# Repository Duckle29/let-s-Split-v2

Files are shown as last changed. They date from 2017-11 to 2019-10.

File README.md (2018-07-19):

# This repo is now an archive. Further boards and development can be found here: https://github.com/Duckle29/Vitamins-included

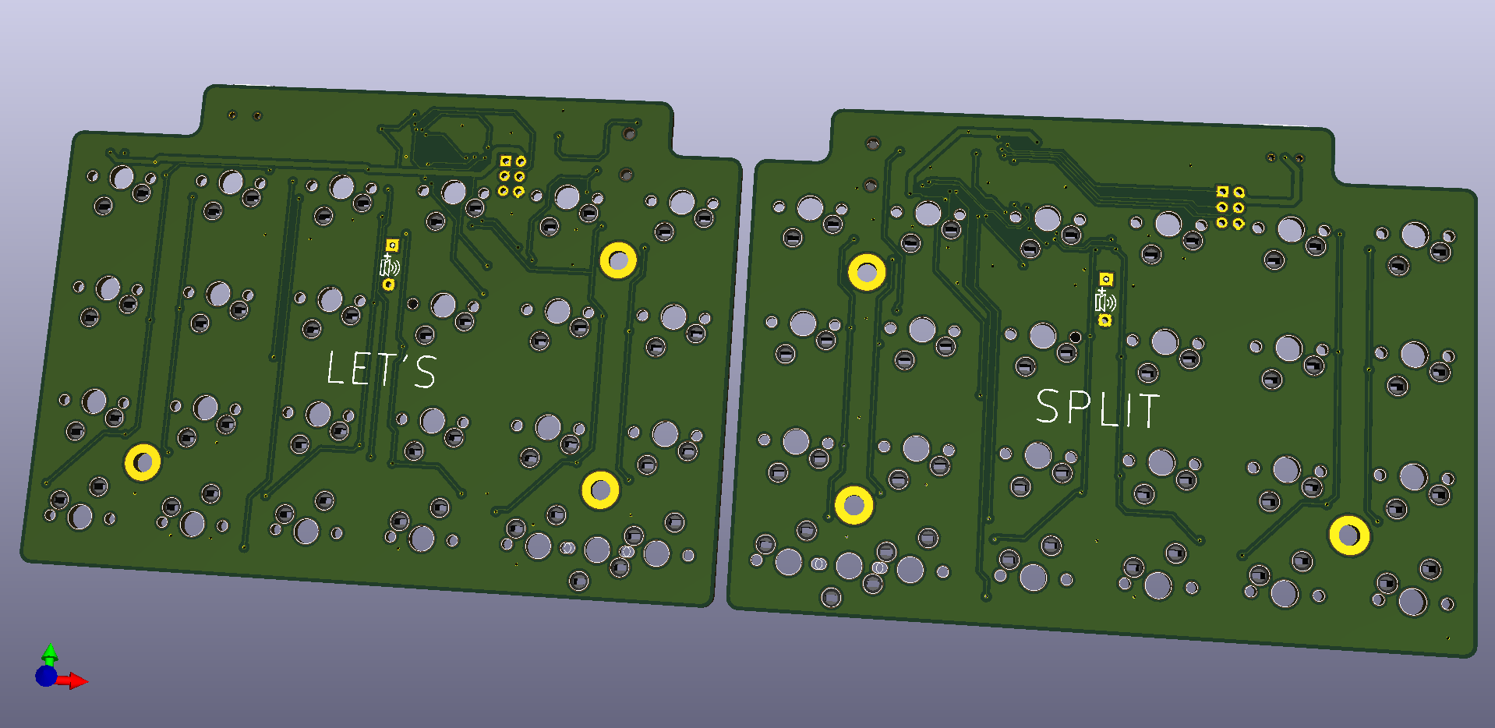
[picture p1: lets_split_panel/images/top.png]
Image of front side of panel

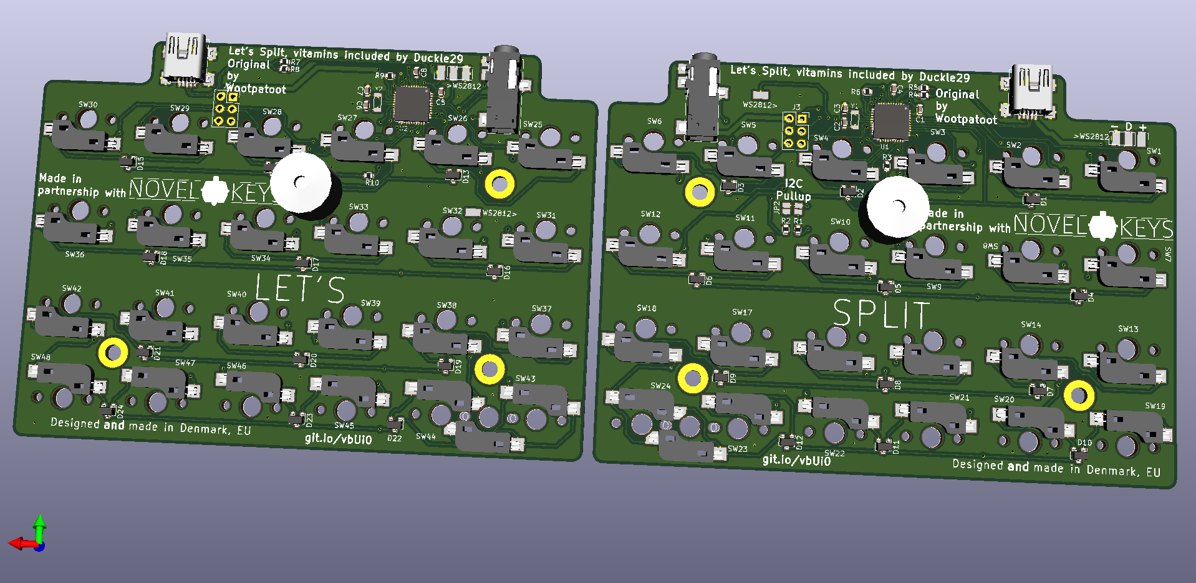
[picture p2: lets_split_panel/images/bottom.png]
Image of bottom side of panel


Schematic

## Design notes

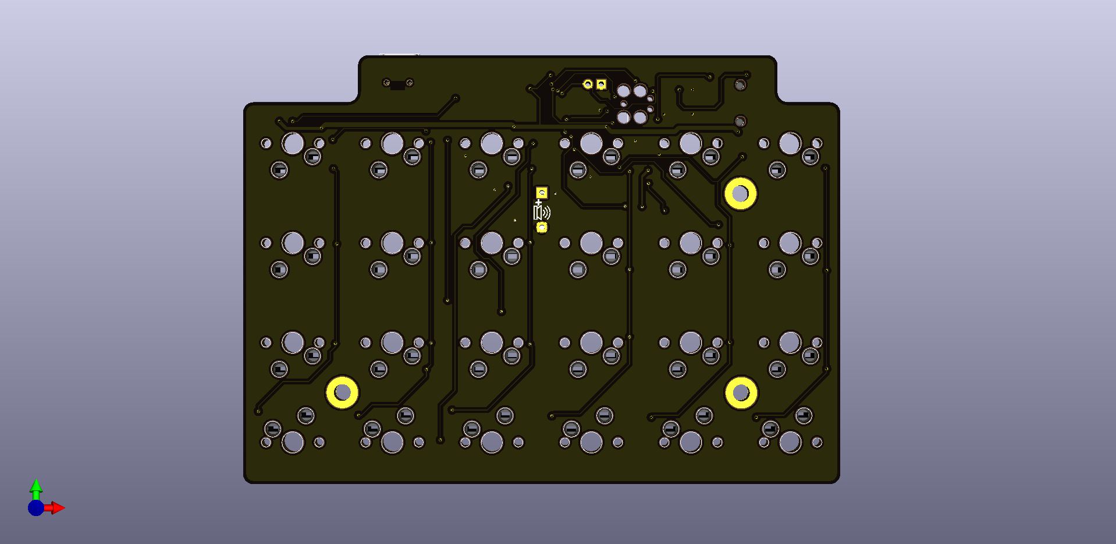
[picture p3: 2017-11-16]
lets_split/images/lets_split-top.png

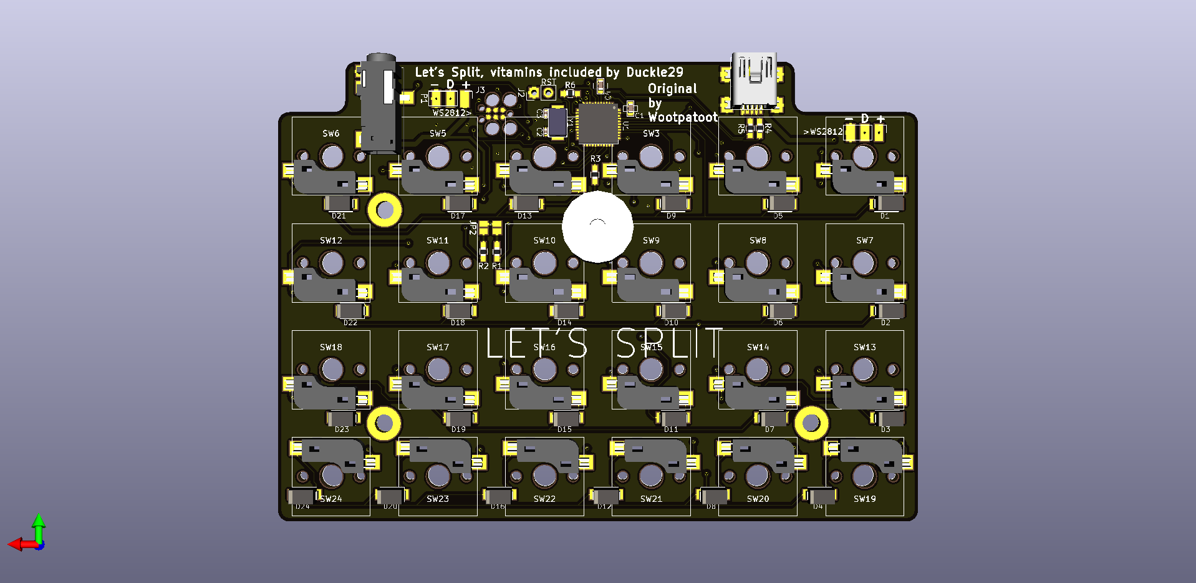
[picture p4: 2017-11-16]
lets_split/images/lets_split-bot.png

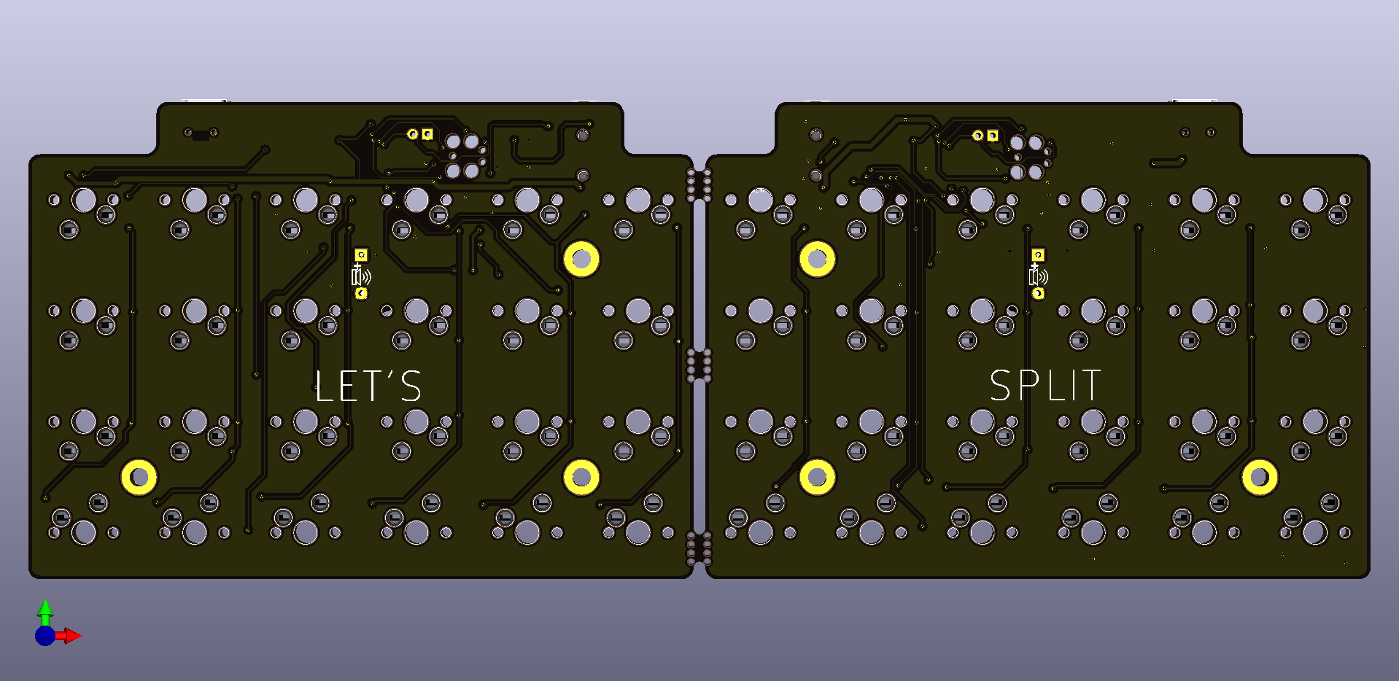
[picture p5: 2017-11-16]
lets_split_panel/images/topside.png

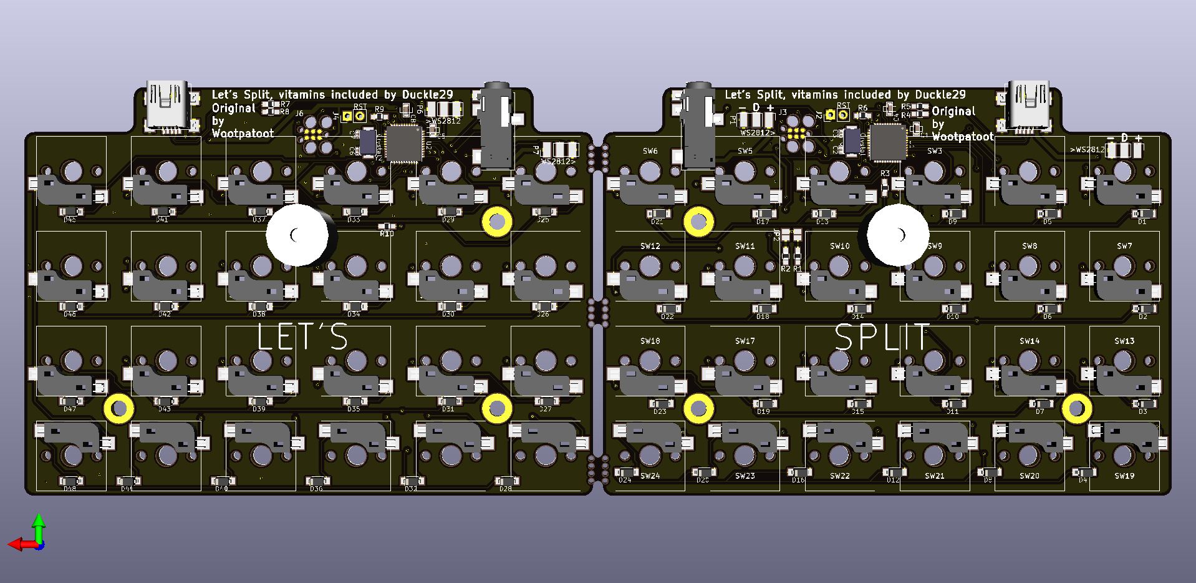
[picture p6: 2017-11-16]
lets_split_panel/images/bottomside.png

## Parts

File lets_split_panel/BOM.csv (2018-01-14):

Id | Designator | Package | Quantity | Designation | Supplier and ref
1 | G***,G*** | kiwi | 2 | LOGO
2 | FID6,FID4,FID5,FID3,FID2,FID1 | Fiducial_1mm_Dia_2mm_Outer | 6 | Fiducial
3 | P5,P2 | USB-Mini-B-SMD | 2 | UJ2-MBH-1-SMT
4 | D21,D16,D23,D14,D20,D22,D19,D24,D17,D15,D13,D18,D2,D8,D6,D12,D3,D7,D10,D4,D9,D11,D5,D1 | SOT-23 | 24 | BAV70
5 | R7,R8,R5,R4 | R_0603 | 4 | 22R
6 | SW40,SW36,SW41,SW43,SW44,SW42,SW45,SW43,SW35,SW28,SW34,SW48,SW47,SW33,SW39,SW32,SW26,SW29,SW46,SW30,SW38,SW27,SW31,SW25,SW37,SW19,SW12,SW21,SW23,SW24,SW24,SW6,SW15,SW4,SW5,SW13,SW20,SW1,SW22,SW16,SW17,SW8,SW10,SW11,SW7,SW9,SW18,SW2,SW14,SW3 | Kailh-socket | 50 | Socket
7 | Y2,Y1 | Crystal_SMD_Abracon_ABM3-2pin_5.0x3.2mm | 2 | 16MHz
8 | P6,P3 | SMD_PAD_1x03_Pitch2.54mm | 2 | >WS2812
9 | P8,P4 | SJ-4351X-SMT | 2 | SJ-43514-SMT
10 | J8,J7 | Pin_Header_Straight_1x01_Pitch2.54mm | 2 | WS2812>
11 | C6,C7,C2,C3 | C_0603 | 4 | 18pF
12 | C5,C8,C1,C4 | C_0603 | 4 | 1uF
13 | REF**,REF**,REF**,REF**,REF**,REF** | 1pin | 6 | 1pin
14 | U2,U1 | QFN44G-0.5-7X7MM | 2 | ATMega32U4
15 | R10,R3 | R_0603 | 2 | 200R
16 | R9,R1,R2,R6 | R_0603 | 4 | 4k7
17 | J6,J3 | Pin_Header_Straight_2x03_Pitch2.54mm | 2 | ISP
18 | J5,J1 | Buzzer_12x9.5RM7.6 | 2 | Speaker
19 | G***,G*** | NovelKeys | 2 | LOGO
20 | JP1,JP2 | Solder-jumper-NO | 2 | I2C pullup

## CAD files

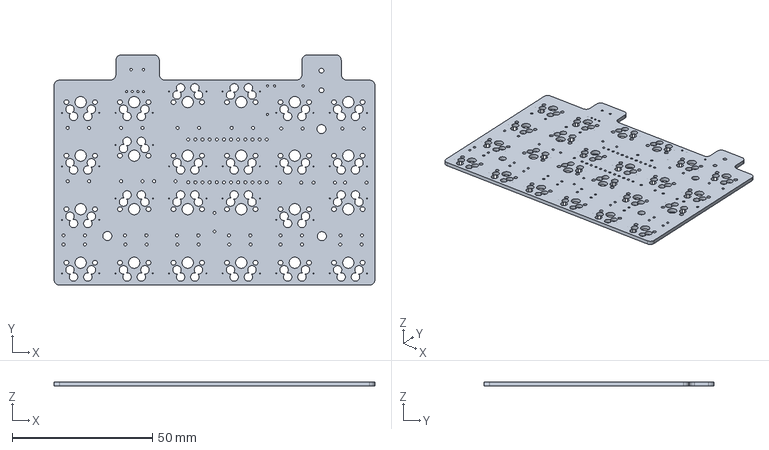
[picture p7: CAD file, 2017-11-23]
lets_split/pcb.step
114.2 x 82.0 x 1.60 mm

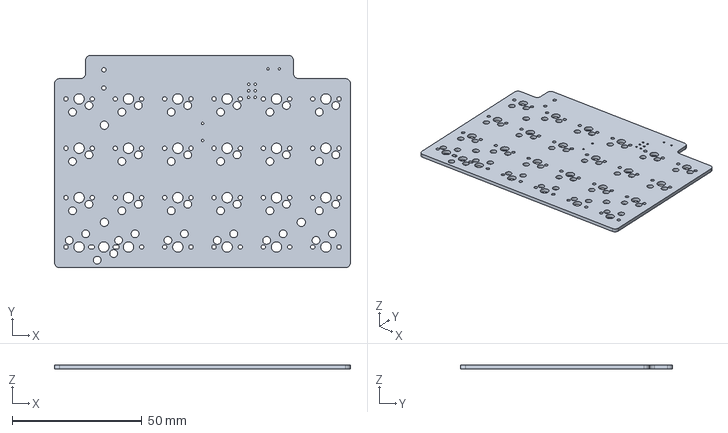
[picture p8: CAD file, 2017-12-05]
lets_split_panel/lets_split_righthalfpanel.stp
114.2 x 82.0 x 1.60 mm

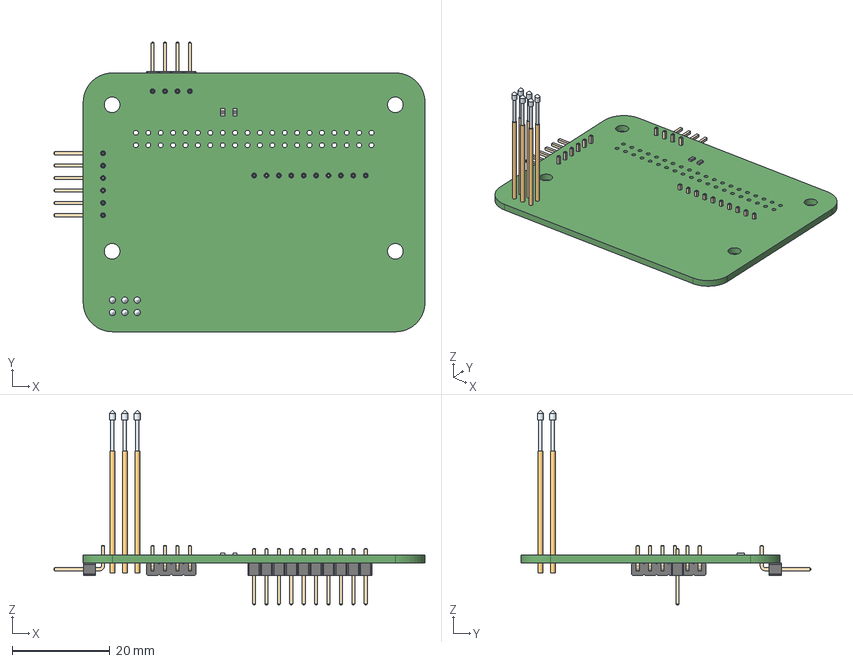
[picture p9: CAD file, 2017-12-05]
lets_split_panel/Programming-jig/prog-jig.stp
76.0 x 59.3 x 39.8 mm
Socket_Strip_Straight_2x20_Pitch2.54mm

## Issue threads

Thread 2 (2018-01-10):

Questions about the latest version

geripgeri, 2018-01-10:
Hi!

First of all, thanks for your work!

I would like to order the PCB via https://jlcpcb.com/
I don't really understand the main differences between version 2 and version 3, could you please describe them to me? Also, is the version 3 branch stabile and working? Do you recommend to use version 3?

Another question: is the version 3 branch compatible with Gateron 5 pin Switches? (Sorry for the noob question, this will be my first DIY keyboard) Can I attach led to the switches? I don't see any holes for leds, Are there any solutions for that?
Like this: 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

Thank you!

Duckle29, 2018-01-10:
Hey there. The latest stable is onboardMCU and I actually have a batch of those on their way, so if you don't want to solder, then those are soon ready.

They, like the V3, don't support in switch LEDs though, but if you know KiCAD it shouldn't be a big change. Just get the source files, and make a footprint for sockets + leds, then update all switches to that footprint, and then re-route the traces. Should be doable in an hour or two.

I will probably be looking into leds if I make any further versions :)

Duckle29, 2018-01-10:
Also, V3 adds the mini-usb breakout, so that your cable can come out the back of the keyboard:

https://i.imgur.com/UIVkkyn.jpg

geripgeri, 2018-01-11:
Thank you for the response!

I think this question has been overlooked:
> Another question: is the version 3 branch compatible with Gateron 5 pin Switches?

I checked the `onboardMCU` branch, looks pretty cool :+1: I can't find the assembly docs, parts list here: https://github.com/Duckle29/lets-split-guide is this because the mentioned batch is the first?

> I actually have a batch of those on their way, so if you don't want to solder, then those are soon ready.
Could you please send me an email about the details? :slightly_smiling_face:

Duckle29, 2018-01-11:
Yes, it's the first batch :) When you mentioned Gateron 5 pin switches, I assume you mean any MX switch with LEDs in them right? That's why I mentioned LEDs :)

geripgeri, 2018-01-12:
> I actually have a batch of those on their way, so if you don't want to solder, then those are soon ready.

Could you please send me an email about the details? 🙂 My email address is visible on my GitHub profile.

No, I meant this: 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

geripgeri, 2018-01-12:
Also, What is the difference between (in onboardMCU branch) `lets_split` and `lets_split_panel` folder?

Duckle29, 2018-01-12:
Ahh those. AFAIK those are just PCB mounted switches, and yes. Those are actually preferred! :)

lets_split_panel was the first batch, where I made the PCBs but not mirrored / flippable, so I had to panelize them. Fucked up and had the switches on the bottom of the keyboard on the right-side by accident, so gave up and decided to make the mirrorable design instead.

Duckle29, 2018-01-12:
Also, for the vitamins included batch. Expect to see it late feb :)

geripgeri, 2018-01-12:
Thanks for the info!

Can you please write down the components of the onboardMCU? Maybe it's better if you write it to the guide repository : I would like to estimate the costs of the PCB.

Duckle29, 2018-01-14:
I can upload the position files that I sent the Pick and place house, it has component names in there iirc.

Duckle29, 2018-01-14:
Done https://github.com/Duckle29/let-s-Split-v2/commit/f37b36a4e8799997df2698dced4c34b87e96ebc7

geripgeri, 2018-01-15:
Thank you!
In the meantime, there is a sale on https://jlcpcb.com
I have a few more questions about the PCB ordering, can I please contact you directly? I don't want to spam the GitHub issue. Could you please send me an email?

Duckle29, 2018-01-21:
@geripgeri Hey man, I don't mind the chat in here :) That way questions can help others

thesourmango, 2018-03-29:
Nice to see you chatting here, I had pretty much the same questions.
I'm dreaming of adding a bottom row, making it 60% and making both halves wireless... #endgame?

I found a wireless lets-split called Trident (https://github.com/YCF/Trident) but it seemed to have some issues, and I'm not comfortable or familiar with the Mitosis firmware it seemed to be running.
Also no sockets.

Anyway, It's been a couple months, have any onboardMCU boards to sell? If not, have you ran into any issues with the current design?

Is there anyone working on an open source 60% wireless socketed split? Like [this](https://www.reddit.com/r/mechmarket/comments/7ywlmb/gb_40_60_and_70_wireless_split_ortholinear/) but open source (and socketed)? No offense to southpaw intended, most of us need to make a living :p

Keep up the awesome work!

Duckle29, 2018-03-29:
@thesourmango Hey there :) The onboard MCU boards are most likely going to be called Vitamins Included, and will be sold by Novelkeys some time in april if everything goes to plan :) Mike is currently working on having cases made for them, which is one issue I've had with these boards. Due to the switches being socketed, you can't rely on them to hold the PCB in place, so the plate and the PCB have to be fixed.

I also haven't put a diode between VCC and VBUS, which gave me some headache in firmware support, but I have since manged to solve that fully in my opinion :) Hell, in the process I even made RGB work regardless of which half is plugged in.

As for a dual wireless, that's very very interesting, and is in fact something I'm working on :)
Currently I'm a bit pressed for time (Job hunting, studying for EE, and looking for sponsors for a LAN event sucks the time out of the schedule :) )

If you're curious, I've been looking at using the adafruit bluefruit NRF52 based board, but I might look for cheaper options. Regardless I'll have to write a new firmware from scratch, or need a lot of help to port QMK :)

thesourmango, 2018-03-29:
Nice, I'll keep an eye out for Vitamins Included! Although I'd want to build mine from the PCB up!
I think it's awesome you're going this way, first open source, then when it works, provide a kit or a full package.

RGB? Oh yes, please upload the pcb files with pads for leds :sweat_smile:  :drooling_face:

I don't suppose there's anything I can help you with the wireless 60% split? You haven't opened a git for it yet? :wink:  (Last year Embedded Student from Finland, ... turn it into my masters project?)

I love ortho for the looks, something magical about two squares on the desk. That being said, there are  some problems moving back and forth from an ANSI ortho to ISO Nordic Staggered when programming. :smile: So I'm now wondering if staggered would make more sense..

The mistel barocco RGB is pretty nice, the price tag isn't even that bad. [The Uruk](https://www.reddit.com/r/MechanicalKeyboards/comments/6nbvdu/ic_the_uruk_a_65_staggered_split_board/) is in development, but I'm a strong believer that the backspace is supposed to be the key in the top-right corner, so that one is out of question for me :smiley:. Also I didn't find any mention of publishing his designs.. :confused:

Duckle29, 2018-03-29:
@thesourmango You can see some images of the board here :) https://imgur.com/a/sle0V

The RGB is for underglow, not for per-key RGB, but I might look in to that in the future. I have to find some backfire LEDs though, so I can keep the boards single sided load (only components on one side) as going dual-sided drives up cost. I know kaihua makes some, so I might try and get in touch there.

I'm also not quite sure if the next board will be QMK based. It might be, or it might be KiiBohd based, or custom firmware. We'll see :)

As for a repo on it, You're right. There isn't one, because I've only gotten as far as buying a bluefruit from adafruit ;)

As for the URUK, that looks sweet :)

rockydbull, 2018-04-24:
Any chance you have a part number for the trrs socket and mini usb port? I am looking to order some blank pcbs and give these a run as macropads.

geripgeri, 2018-05-04:
@Duckle29 Hi!

>  @thesourmango Hey there :) The onboard MCU boards are most likely going to be called Vitamins Included, and will be sold by Novelkeys some time in April if everything goes to plan :) Mike is currently working on having cases made for them, which is one issue I've had with these boards. Due to the switches being socketed, you can't rely on them to hold the PCB in place, so the plate and the PCB have to be fixed.

Based on your previous comment, is there any chance to buy the onboardMCU version from novelkeys?

Unfortunately I only see this product, the old design.

https://novelkeys.xyz/collections/diy-kits/products/kailh-choc-lets-split-kit

Duckle29, 2018-05-04:
@geripgeri https://www.instagram.com/p/Bh2E833D8qm/ :)

geripgeri, 2018-05-05:
Nice :+1:  Thank you!

fi0, 2018-05-29:
@geripgeri not sure if this is the updated version. https://github.com/Duckle29/let-s-Split-v2/blob/f37b36a4e8799997df2698dced4c34b87e96ebc7/lets_split_panel/BOM.csv

geripgeri, 2018-05-29:
@fi0 As far as I know that is the latest commit. Am I right @Duckle29 ?

daysgobye, 2018-11-16:
@Duckle29 I just ordered some pcbs and trying to order other parts now. what trrs jacks does it the pcb use? from the files, it looks like smd jacks but im not sure. Any help would be appreciated. Also, thank you for the work you did!

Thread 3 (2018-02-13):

Kailh sockets?

gwerbin, 2018-02-13:
I saw on Youtube you were considering making a version of this board that could use the Kailh hotswap sockets. Is that available in this repo?

Duckle29, 2018-02-13:
Yea it's the V3 and the onboardMCU is kailh. Give it a few weeks and there should be 100 boards for sale at novelkeys :)

gwerbin, 2018-02-13:
@Duckle29 that's fantastic news.

Do the Kailh sockets work with the Outemu and BSUN pre-socketed switches? I assume I need to remove the outer socket first, but then will it still fit? As I understand it, the pin inside those sockets is much smaller and rounder than a typical switch pin (which is why you can't use other switches with them).

Duckle29, 2018-02-13:
I don't think so, but if I were you I'd get a few kailh sockets, and test it. You can get the sockets from novelkeys, I haven't found anyone else who stock them

gwerbin, 2018-02-14:
@Duckle29 order placed. I'll let you know how it goes.

Duckle29, 2018-04-04:
@gwerbin Any news on the kailh sockets? Could be cool to know :)

gwerbin, 2018-04-04:
The sockets seem to work fine. The pins aren't *that* much smaller.

Duckle29, 2018-04-04:
Cool. Good to know. I'll close this issue then :)

Closed 2018-04-04.

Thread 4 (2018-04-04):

pads in socket reversible

fi0, 2018-04-04:
https://imgur.com/a/NltYr

Hi - not sure if this is the right place to ask. I'm learning KiCad.
What're the benefits of adding these pads?

thank you :)

Duckle29, 2018-04-04:
Hello there. No problem :) The layout you are looking at is reverseable, that is, the sockets can be soldered to either side. This means that instead of ordering 20 left halves, and 20 right halves, I can order 40 halves, and get better prices :) The layout is just the normal layout flipped :)

fi0, 2018-04-04:
thank you :)

Closed 2018-04-04.

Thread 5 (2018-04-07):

Onboard without diodes

fi0, 2018-04-07:
There're 26 pins in Atmega32U4. Do you think it's possible to build it without diodes? What're the pros and cons?

Duckle29, 2018-04-08:
Why would you want to do it without diodes? You might be able to, but why?

fi0, 2018-04-09:
Just for learning purpose. But the traces would be longer.

Closed 2018-05-29.

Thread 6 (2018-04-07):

onboardMCU branch missing pads

fi0, 2018-04-07:
https://imgur.com/a/22Cqy

Pads seems to be missing in the PadsFront layer.

Duckle29, 2018-04-08:
Which pads? Do you mean for the segger j-link probe? I moved away from that after seeing how expensive the probes are :)

Duckle29, 2018-04-08:
These ones: https://www.segger.com/products/debug-probes/j-link/accessories/adapters/6-pin-needle-adapter/

fi0, 2018-04-08:
For the USB port and TRRS, I can see the pads on one side only.

Duckle29, 2018-04-08:
Oh, you're probably looking at an old branch

Duckle29, 2018-04-08:
Oh that's the onboard MCU, it's made for cheap production, that means everything is on one side.

fi0, 2018-04-09:
Should I look into the `lets_split` or `lets_split_panel` in the onboardMCU branch? or both?

Closed 2018-05-29.

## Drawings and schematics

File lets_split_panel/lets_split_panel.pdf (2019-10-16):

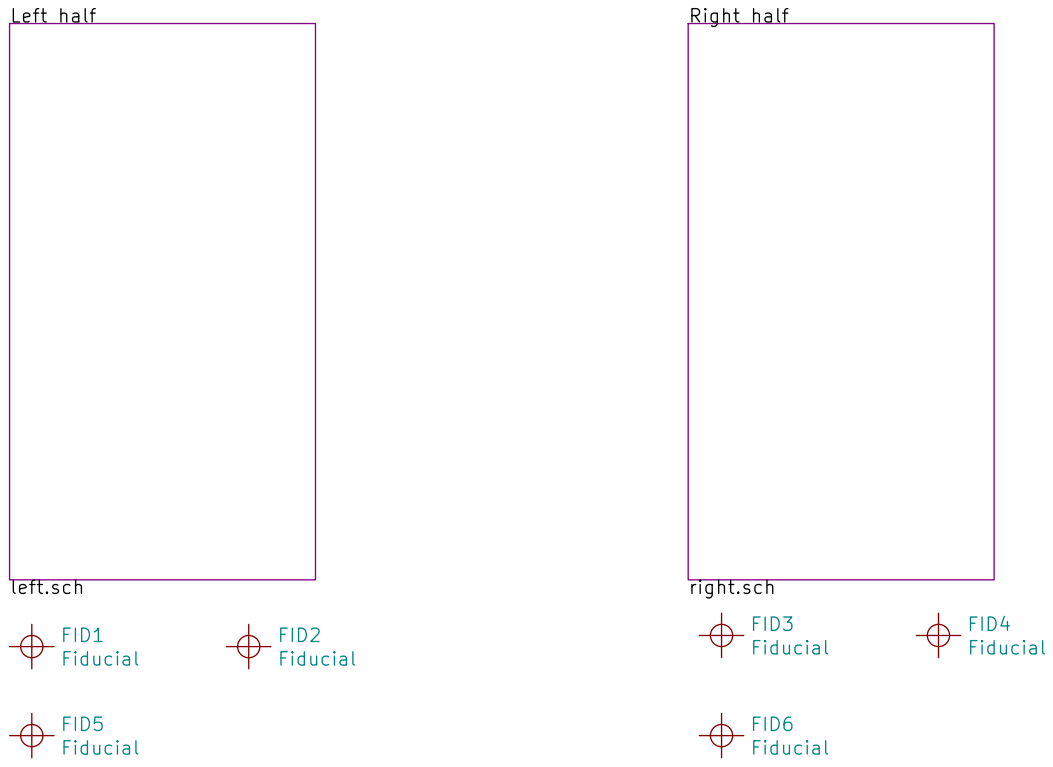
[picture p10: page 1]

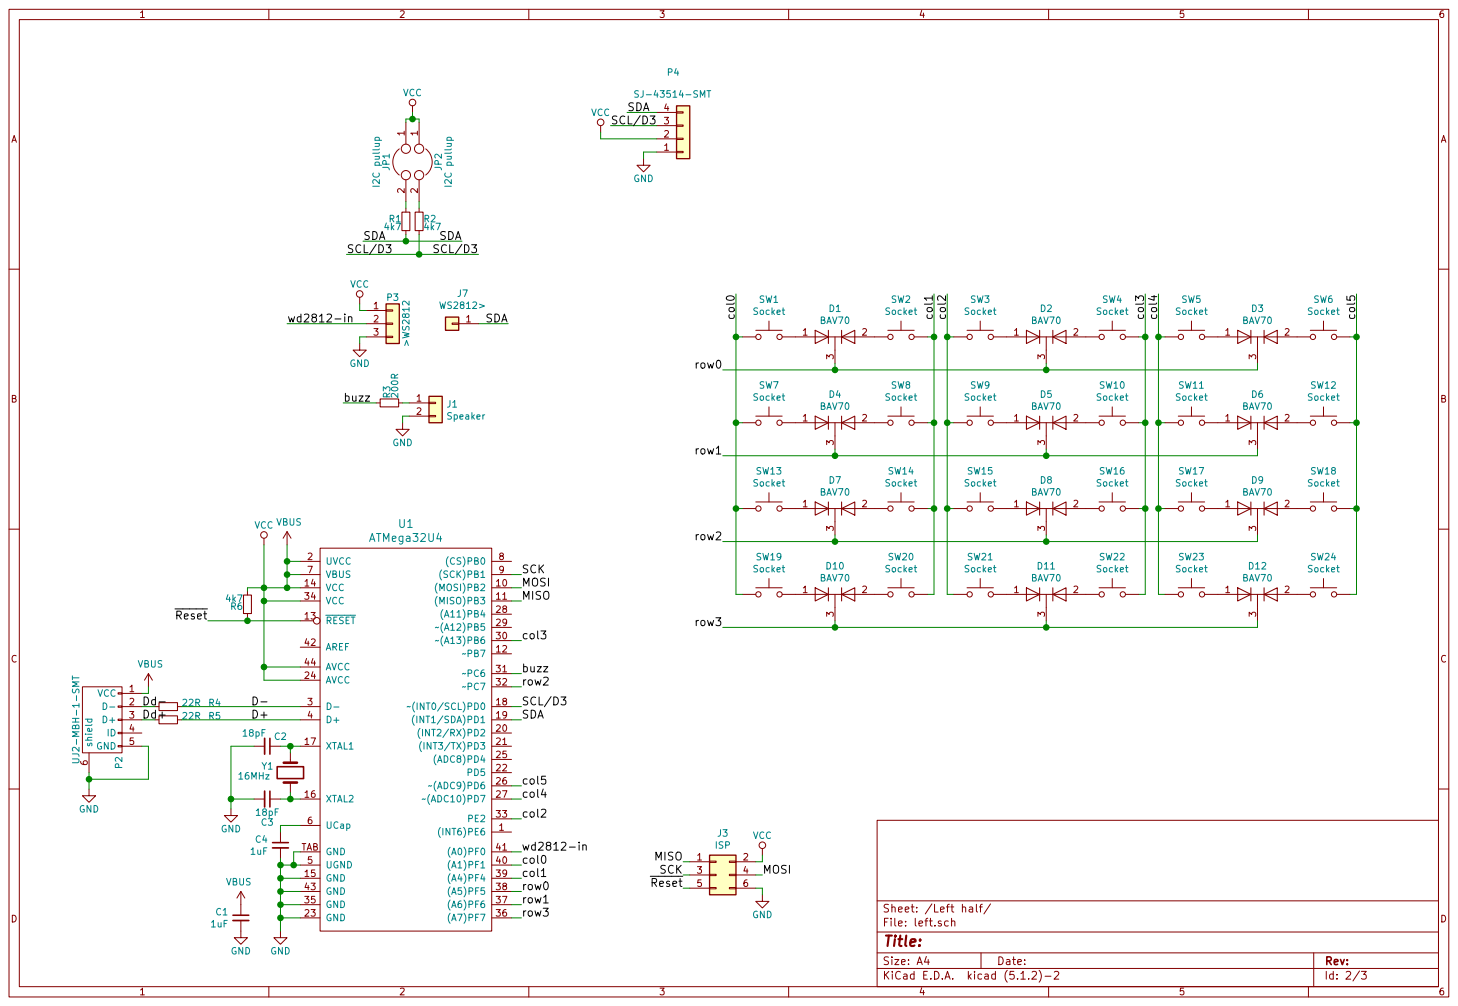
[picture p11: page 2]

Id: 2/3 Title: File: left.sch Sheet: /Left half/

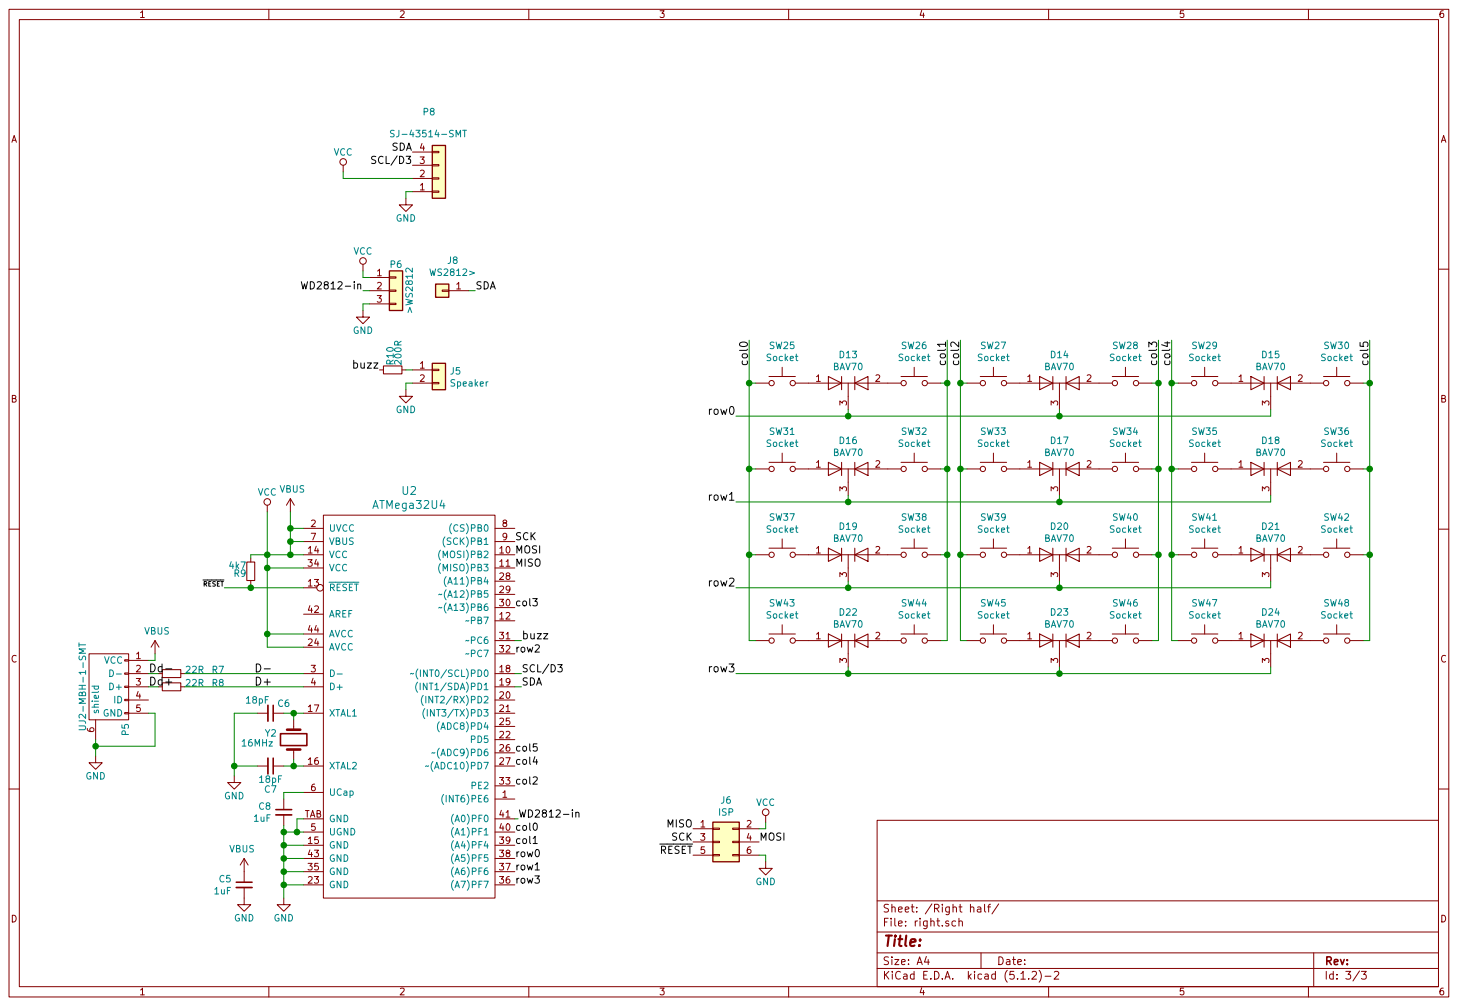
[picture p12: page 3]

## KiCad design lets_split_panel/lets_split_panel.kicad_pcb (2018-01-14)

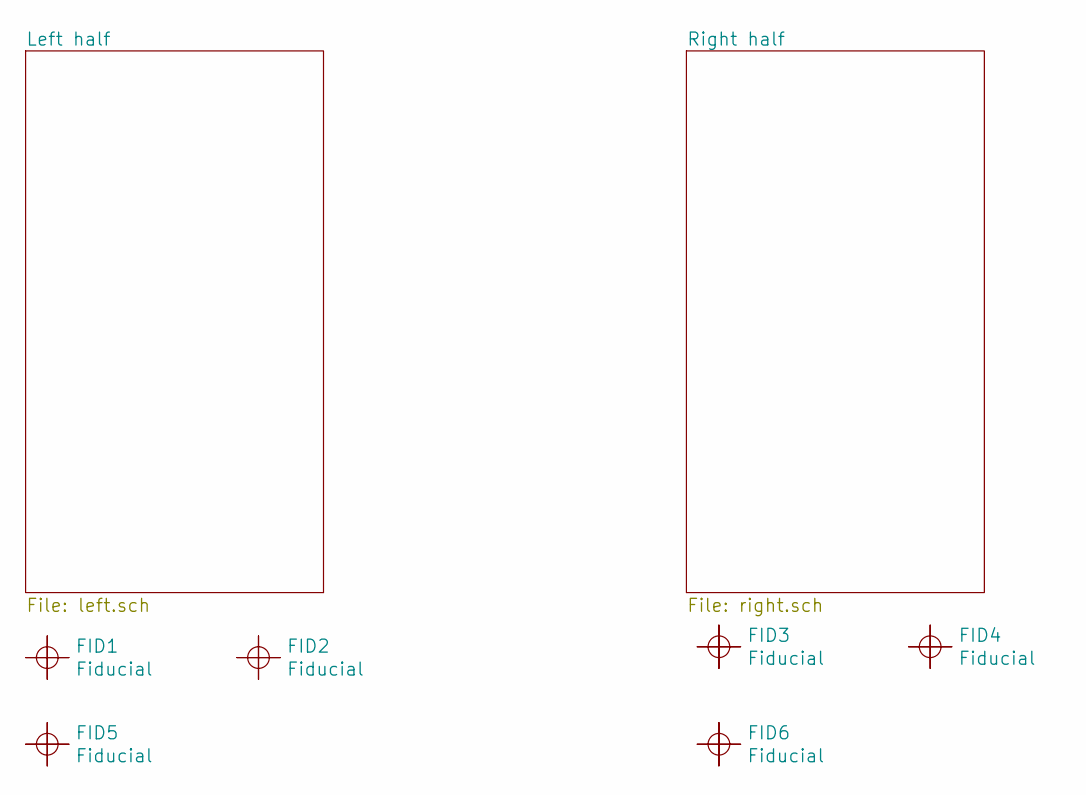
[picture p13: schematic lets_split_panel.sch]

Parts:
FID1, FID2, FID3, FID4, FID5, FID6: Fiducial; Fiducial_1mm_Dia_2mm_Outer

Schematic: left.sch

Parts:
C1, C4: 1uF; C_0603
C2, C3: 18pF; C_0603
D1, D2, D3, D4, D5, D6, D7, D8, D9, D10, D11, D12: BAV70; SOT-23
J1: Speaker; Buzzer_12x9.5RM7.6
J3: ISP; Pin_Header_Straight_2x03_Pitch2.54mm
J7: WS2812>; Pin_Header_Straight_1x01_Pitch2.54mm
JP1, JP2: I2C pullup; Solder-jumper-NO
P2: UJ2-MBH-1-SMT; USB-Mini-B-SMD
P3: >WS2812; SMD_PAD_1x03_Pitch2.54mm
P4: SJ-43514-SMT; SJ-4351X-SMT
R1, R2, R6: 4k7; R_0603
R3: 200R; R_0603
R4, R5: 22R; R_0603
SW1, SW2, SW3, SW4, SW5, SW6, SW7, SW8, SW9, SW10, SW11, SW12, SW13, SW14, SW15, SW16, SW17, SW18, SW19, SW20, SW21, SW22, SW23, SW24: Socket; Kailh-socket
U1: ATMega32U4; QFN44G-0.5-7X7MM
Y1: 16MHz; Crystal_SMD_Abracon_ABM3-2pin_5.0x3.2mm

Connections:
/Left half/D+: R5.2, U1.4 (D+)
/Left half/D-: R4.2, U1.3 (D-)
/Left half/Dd+: P2.3 (D+), R5.1
/Left half/Dd-: P2.2 (D-), R4.1
/Left half/MISO: J3.1, U1.11 ((MISO)PB3)
/Left half/MOSI: J3.4, U1.10 ((MOSI)PB2)
/Left half/SCK: J3.3, U1.9 ((SCK)PB1)
/Left half/SCL/D3: P4.3, R2.2, U1.18 (~~(INT0/SCL)PD0)
/Left half/SDA: J7.1, P4.4, R1.2, U1.19 ((INT1/SDA)PD1)
/Left half/buzz: R3.1, U1.31 (~~PC6)
/Left half/col0: SW1.1, SW7.1, SW13.1, SW19.1, U1.40 ((A1)PF1)
/Left half/col1: SW2.2, SW8.2, SW14.2, SW20.2, U1.39 ((A4)PF4)
/Left half/col2: SW3.1, SW9.1, SW15.1, SW21.1, U1.33 (PE2)
/Left half/col3: SW4.2, SW10.2, SW16.2, SW22.2, U1.30 (~~(A13)PB6)
/Left half/col4: SW5.1, SW11.1, SW17.1, SW23.1, U1.27 (~~(ADC10)PD7)
/Left half/col5: SW6.2, SW12.2, SW18.2, SW24.2, U1.26 (~~(ADC9)PD6); also elsewhere on the board
/Left half/row0: D1.3, D2.3, D3.3, U1.38 ((A5)PF5)
/Left half/row1: D4.3, D5.3, D6.3, U1.37 ((A6)PF6)
/Left half/row2: D7.3, D8.3, D9.3, U1.32 (~~PC7)
/Left half/row3: D10.3, D11.3, D12.3, U1.36 ((A7)PF7)
/Left half/wd2812-in: P3.2, U1.41 ((A0)PF0)
/Left half/~Reset: J3.5, R6.1, U1.13 (~RESET~)
GND: C1.2, C2.2, C3.2, C4.2, J1.2, J3.6, P2.5 (GND), P2.6 (shield), P3.3, P4.1, U1.5 (UGND), U1.15 (GND), U1.23 (GND), U1.35 (GND), U1.43 (GND), U1.TAB (GND); also elsewhere on the board
unnamed: C2.1, U1.17 (XTAL1), Y1.1
unnamed: C3.1, U1.16 (XTAL2), Y1.2
unnamed: C4.1, U1.6 (UCap)
unnamed: D1.1, SW1.2
unnamed: D1.2, SW2.1
unnamed: D2.1, SW3.2
unnamed: D2.2, SW4.1
unnamed: D3.1, SW5.2
unnamed: D3.2, SW6.1
unnamed: D4.1, SW7.2
unnamed: D4.2, SW8.1
unnamed: D5.1, SW9.2
unnamed: D5.2, SW10.1
unnamed: D6.1, SW11.2
unnamed: D6.2, SW12.1
unnamed: D7.1, SW13.2
unnamed: D7.2, SW14.1
unnamed: D8.1, SW15.2
unnamed: D8.2, SW16.1
unnamed: D9.1, SW17.2
unnamed: D9.2, SW18.1
unnamed: D10.1, SW19.2
unnamed: D10.2, SW20.1
unnamed: D11.1, SW21.2
unnamed: D11.2, SW22.1
unnamed: D12.1, SW23.2
unnamed 74: D12.2, SW24.1; also elsewhere on the board
unnamed: J1.1, R3.2
unnamed: JP1.2, R1.1
unnamed: JP2.2, R2.1
VBUS: C1.1, J3.2, JP1.1, JP2.1, P2.1 (VCC), P3.1, P4.2, R6.2, U1.2 (UVCC), U1.7 (VBUS), U1.14 (VCC), U1.24 (AVCC), U1.34 (VCC), U1.44 (AVCC); also elsewhere on the board

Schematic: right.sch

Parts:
C5, C8: 1uF; C_0603
C6, C7: 18pF; C_0603
D13, D14, D15, D16, D17, D18, D19, D20, D21, D22, D23, D24: BAV70; SOT-23
J5: Speaker; Buzzer_12x9.5RM7.6
J6: ISP; Pin_Header_Straight_2x03_Pitch2.54mm
J8: WS2812>; Pin_Header_Straight_1x01_Pitch2.54mm
P5: UJ2-MBH-1-SMT; USB-Mini-B-SMD
P6: >WS2812; SMD_PAD_1x03_Pitch2.54mm
P8: SJ-43514-SMT; SJ-4351X-SMT
R7, R8: 22R; R_0603
R9: 4k7; R_0603
R10: 200R; R_0603
SW25, SW26, SW27, SW28, SW29, SW30, SW31, SW32, SW33, SW34, SW35, SW36, SW37, SW38, SW39, SW40, SW41, SW42, SW43, SW44, SW45, SW46, SW47, SW48: Socket; Kailh-socket
U2: ATMega32U4; QFN44G-0.5-7X7MM
Y2: 16MHz; Crystal_SMD_Abracon_ABM3-2pin_5.0x3.2mm

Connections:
/Right half/D+: R8.2, U2.4 (D+)
/Right half/D-: R7.2, U2.3 (D-)
/Right half/Dd+: P5.3 (D+), R8.1
/Right half/Dd-: P5.2 (D-), R7.1
/Right half/MISO: J6.1, U2.11 ((MISO)PB3)
/Right half/MOSI: J6.4, U2.10 ((MOSI)PB2)
/Right half/SCK: J6.3, U2.9 ((SCK)PB1)
/Right half/SCL/D3: P8.3, U2.18 (~~(INT0/SCL)PD0)
/Right half/SDA: J8.1, P8.4, U2.19 ((INT1/SDA)PD1)
/Right half/WD2812-in: P6.2, U2.41 ((A0)PF0)
/Right half/buzz: R10.1, U2.31 (~~PC6)
/Right half/col0: SW25.1, SW31.1, SW37.1, SW43.1, U2.40 ((A1)PF1); also elsewhere on the board
/Right half/col1: SW26.2, SW32.2, SW38.2, SW44.2, U2.39 ((A4)PF4)
/Right half/col2: SW27.1, SW33.1, SW39.1, SW45.1, U2.33 (PE2)
/Right half/col3: SW28.2, SW34.2, SW40.2, SW46.2, U2.30 (~~(A13)PB6)
/Right half/col4: SW29.1, SW35.1, SW41.1, SW47.1, U2.27 (~~(ADC10)PD7)
/Right half/col5: SW30.2, SW36.2, SW42.2, SW48.2, U2.26 (~~(ADC9)PD6)
/Right half/row0: D13.3, D14.3, D15.3, U2.38 ((A5)PF5)
/Right half/row1: D16.3, D17.3, D18.3, U2.37 ((A6)PF6)
/Right half/row2: D19.3, D20.3, D21.3, U2.32 (~~PC7)
/Right half/row3: D22.3, D23.3, D24.3, U2.36 ((A7)PF7)
/Right half/~RESET: J6.5, R9.1, U2.13 (~RESET~)
GND: C5.2, C6.2, C7.2, C8.2, J5.2, J6.6, P5.5 (GND), P5.6 (shield), P6.3, P8.1, U2.5 (UGND), U2.15 (GND), U2.23 (GND), U2.35 (GND), U2.43 (GND), U2.TAB (GND); also elsewhere on the board
unnamed: C6.1, U2.17 (XTAL1), Y2.1
unnamed: C7.1, U2.16 (XTAL2), Y2.2
unnamed: C8.1, U2.6 (UCap)
unnamed: D13.1, SW25.2
unnamed: D13.2, SW26.1
unnamed: D14.1, SW27.2
unnamed: D14.2, SW28.1
unnamed: D15.1, SW29.2
unnamed: D15.2, SW30.1
unnamed: D16.1, SW31.2
unnamed: D16.2, SW32.1
unnamed: D17.1, SW33.2
unnamed: D17.2, SW34.1
unnamed: D18.1, SW35.2
unnamed: D18.2, SW36.1
unnamed: D19.1, SW37.2
unnamed: D19.2, SW38.1
unnamed: D20.1, SW39.2
unnamed: D20.2, SW40.1
unnamed: D21.1, SW41.2
unnamed: D21.2, SW42.1
unnamed 93: D22.1, SW43.2; also elsewhere on the board
unnamed: D22.2, SW44.1
unnamed: D23.1, SW45.2
unnamed: D23.2, SW46.1
unnamed: D24.1, SW47.2
unnamed: D24.2, SW48.1
unnamed: J5.1, R10.2
VBUS: C5.1, J6.2, P5.1 (VCC), P6.1, P8.2, R9.2, U2.2 (UVCC), U2.7 (VBUS), U2.14 (VCC), U2.24 (AVCC), U2.34 (VCC), U2.44 (AVCC); also elsewhere on the board

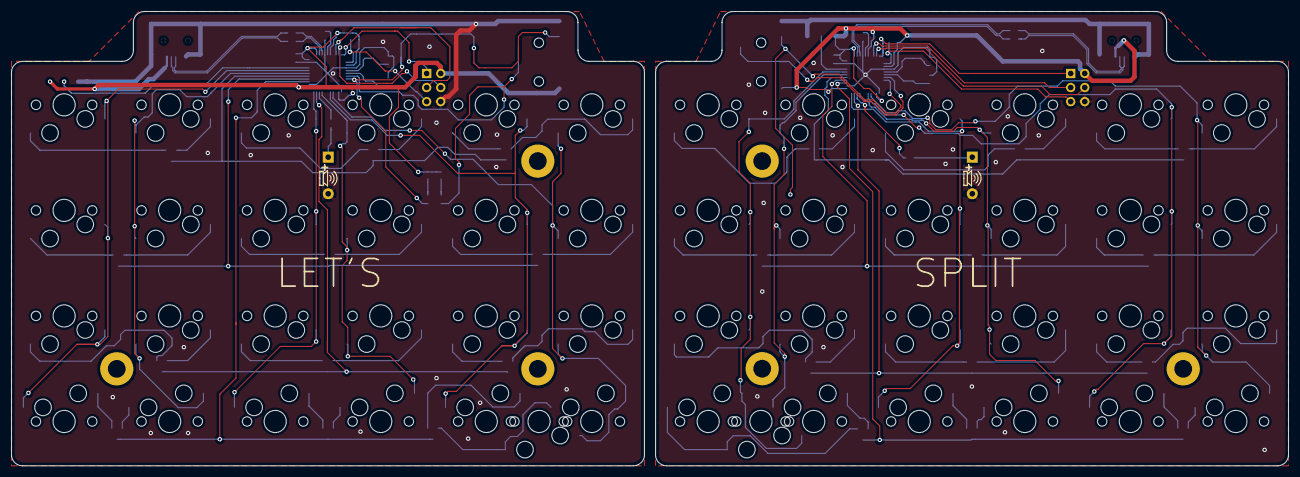
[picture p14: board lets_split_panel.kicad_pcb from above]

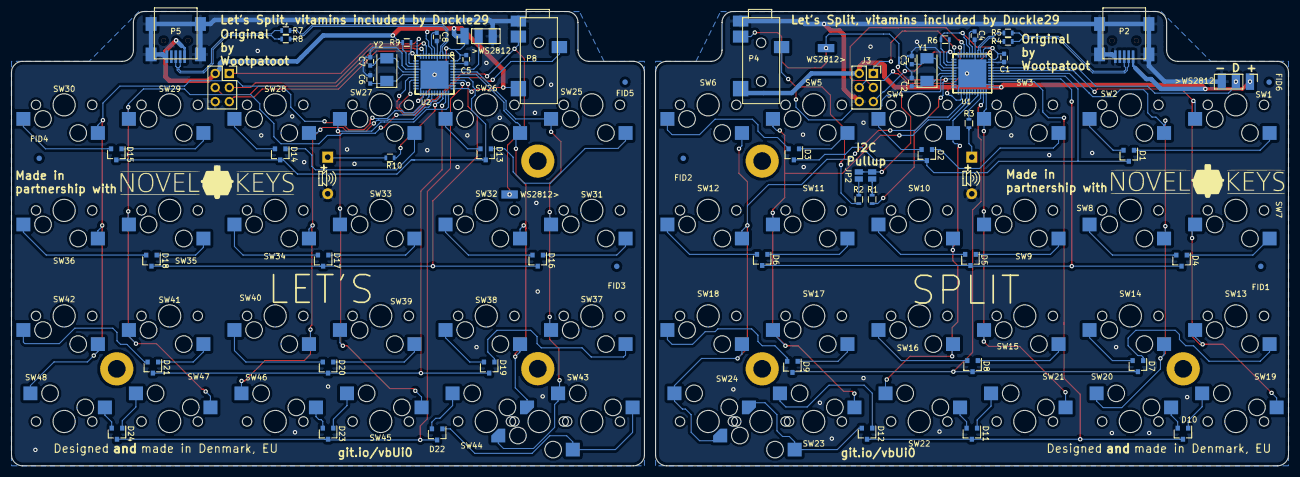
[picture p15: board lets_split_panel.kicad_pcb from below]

Board: 2 copper layers, 230.5 x 82.0 mm, 116 parts (64 on the bottom side), 104 nets.

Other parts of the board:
SW24#2, SW43#2: Socket; Kailh-socket

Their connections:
/Left half/col5: SW24#2.2; also elsewhere on the board
/Right half/col0: SW43#2.1; also elsewhere on the board
unnamed 74: SW24#2.1; also elsewhere on the board
unnamed 93: SW43#2.2; also elsewhere on the board

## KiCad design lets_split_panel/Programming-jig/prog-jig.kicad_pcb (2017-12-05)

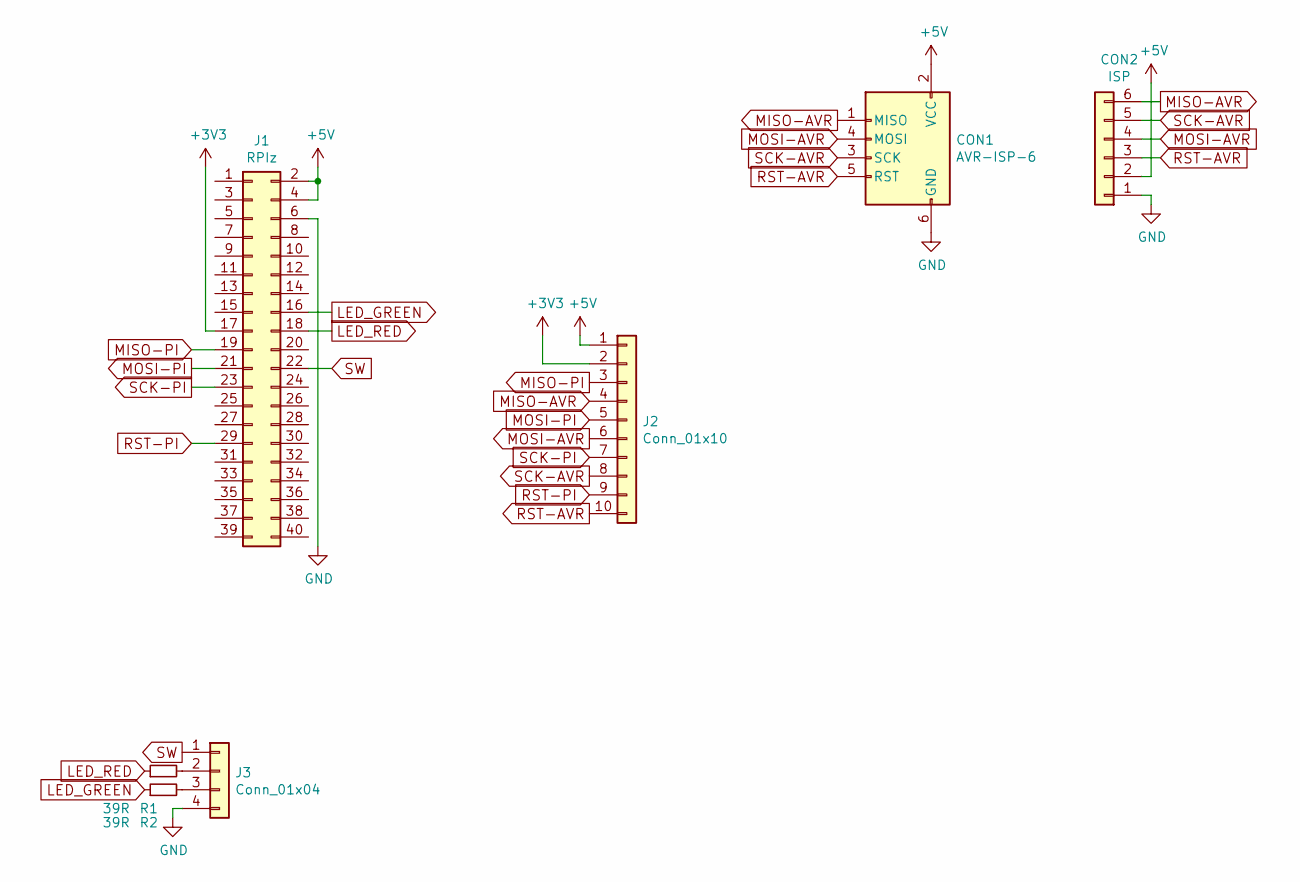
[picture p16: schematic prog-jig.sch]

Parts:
CON1: AVR-ISP-6; Pin_Header_Straight_2x03_Pitch2.54mm
CON2: ISP; Pin_Header_Straight_1x06_Pitch2.54mm
J1: RPIz; Socket_Strip_Straight_2x20_Pitch2.54mm
J2: Conn_01x10; Pin_Header_Straight_1x10_Pitch2.54mm
J3: Conn_01x04; Pin_Header_Angled_1x04_Pitch2.54mm
R1, R2: 39R; R_0603_HandSoldering

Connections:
+3V3: J1.17, J2.2
+5V: CON1.2 (VCC), CON2.2, J1.2, J1.4, J2.1
GND: CON1.6 (GND), CON2.1, J1.6, J3.4
LED_GREEN: J1.16, R2.1
LED_RED: J1.18, R1.1
MISO-AVR: CON1.1 (MISO), CON2.6, J2.4
MISO-PI: J1.19, J2.3
MOSI-AVR: CON1.4 (MOSI), CON2.4, J2.6
MOSI-PI: J1.21, J2.5
unnamed: J3.2, R1.2
unnamed: J3.3, R2.2
RST-AVR: CON1.5 (RST), CON2.3, J2.10
RST-PI: J1.29, J2.9
SCK-AVR: CON1.3 (SCK), CON2.5, J2.8
SCK-PI: J1.23, J2.7
SW: J1.22, J3.1

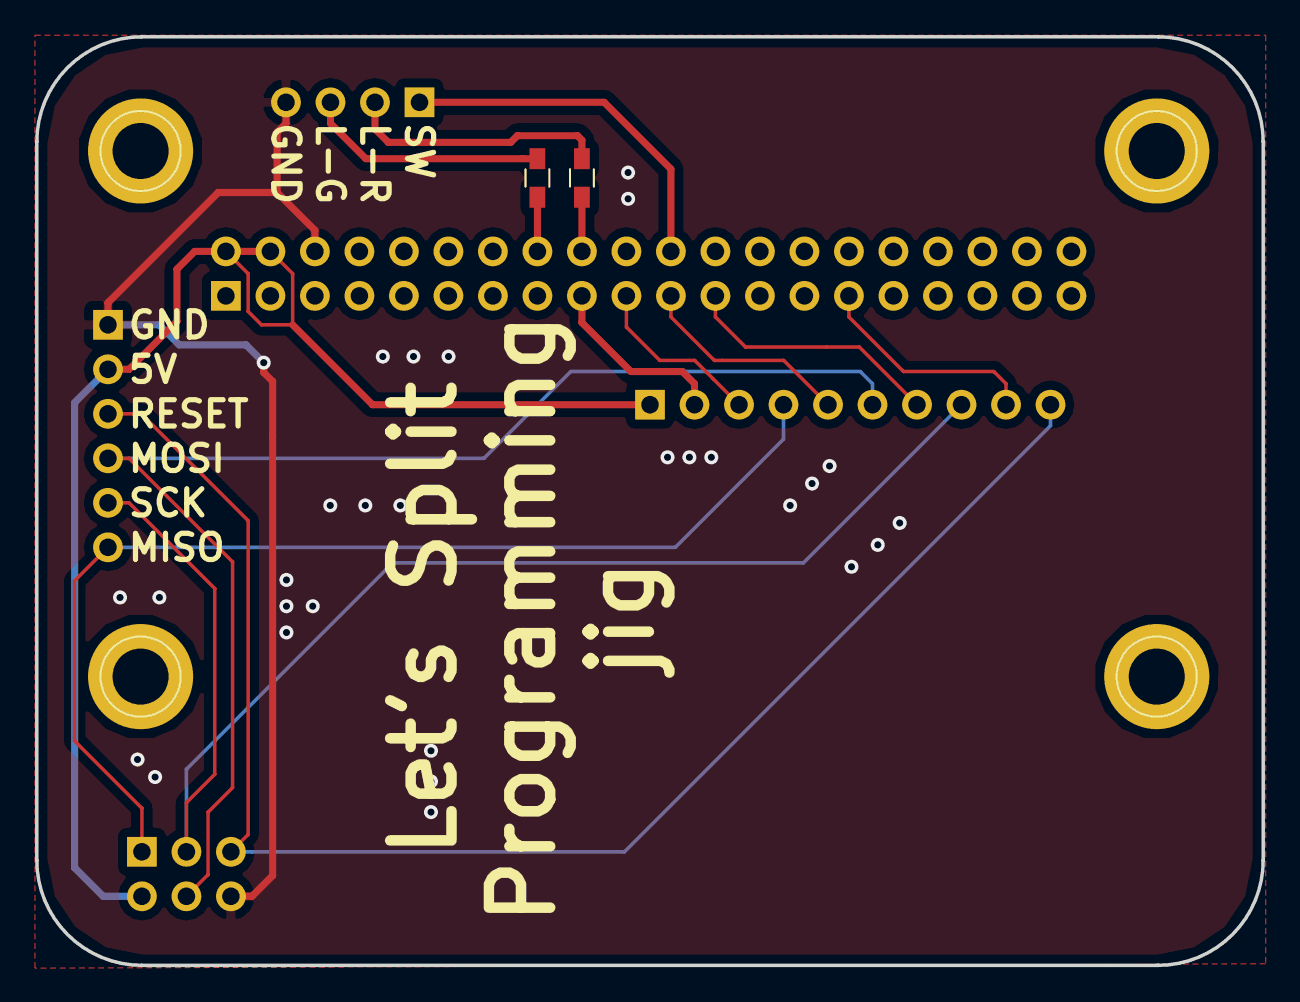
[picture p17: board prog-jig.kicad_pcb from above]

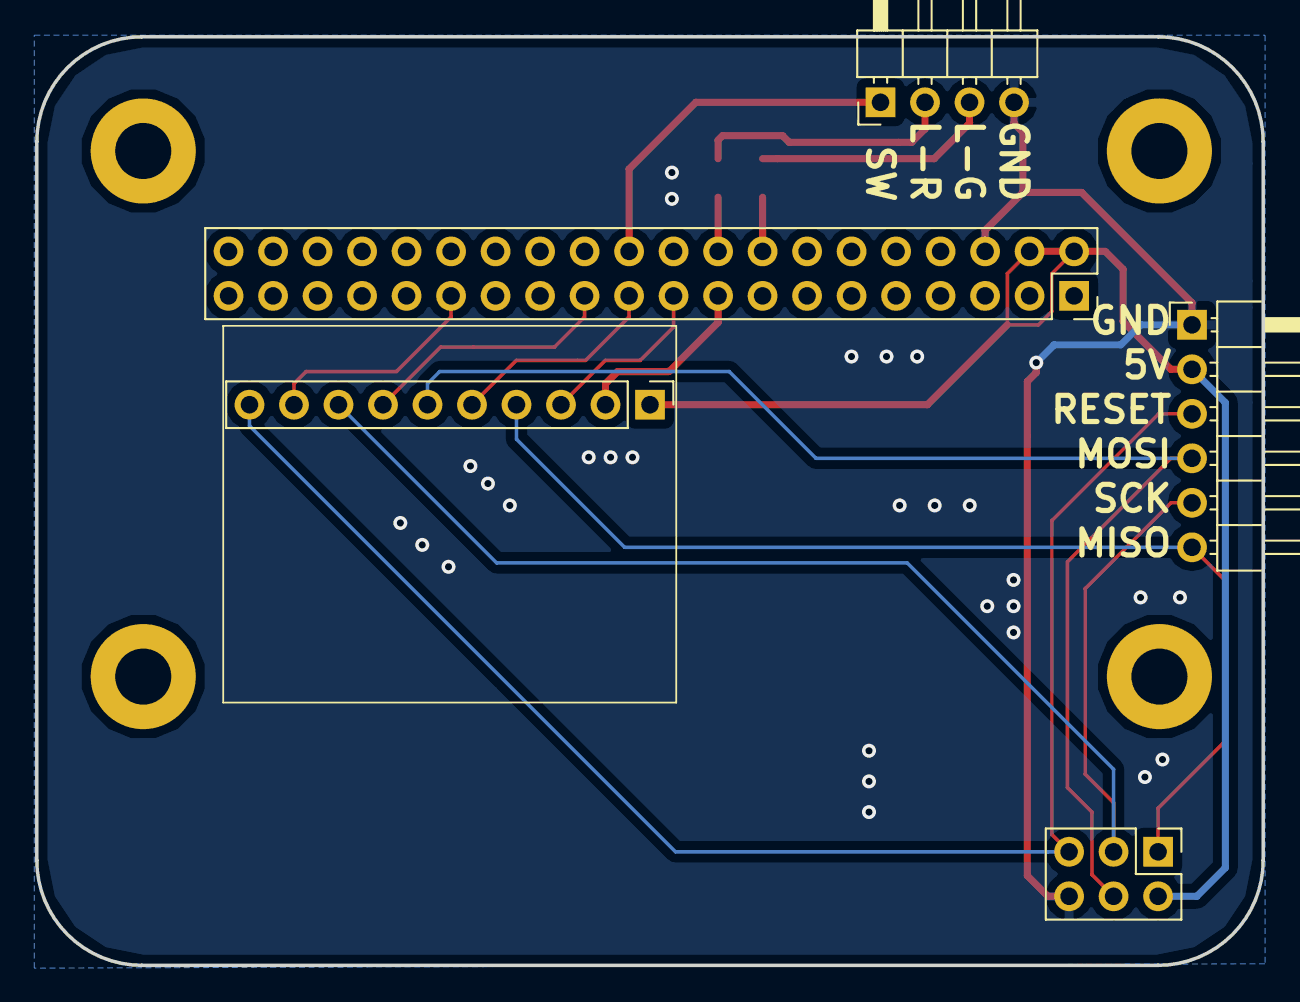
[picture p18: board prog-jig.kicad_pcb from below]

Board: 2 copper layers, 70.0 x 53.0 mm, 7 parts (5 on the bottom side), 16 nets.

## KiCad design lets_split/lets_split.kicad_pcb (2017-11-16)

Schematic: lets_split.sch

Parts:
C1, C4: 1uF; C0603
C2, C3: 8pF; C0402
D1, D2, D3, D4, D5, D6, D7, D8, D9, D10, D11, D12, D13, D14, D15, D16, D17, D18, D19, D20, D21, D22, D23, D24: D; SOD-123
J1: Speaker; Buzzer_12x9.5RM7.6
J2: RST; Pin_Header_Straight_1x02_Pitch2.54mm
J3: ISP; J-link-needle-6pin
JP1, JP2: I2C pullup; Solder-jumper-NO
P1: WS2812>; SMD_PAD_1x03_Pitch2.54mm
P2: USB_OTG; USB-Mini-B-SMD
P3: >WS2812; SMD_PAD_1x03_Pitch2.54mm
P4: Conn_01x04; SJ-4351X-SMT
R1, R2, R6: 4k7; R_0603_HandSoldering
R3: 200; R_0603_HandSoldering
R4, R5: 22R; R_0603_HandSoldering
SW1, SW2, SW3, SW4, SW5, SW6, SW7, SW8, SW9, SW10, SW11, SW12, SW13, SW14, SW15, SW16, SW17, SW18, SW19, SW20, SW21, SW22, SW23, SW24: MXALPS; Kailh-socket
U1: ATMega32U4; QFN44G-0.5-7X7MM
Y1: Crystal; X2-SMD-5.0X3.2X1.3MM

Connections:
/D+: R5.2, U1.4 (D+)
/D-: R4.2, U1.3 (D-)
/MISO: J3.1, U1.11 ((MISO)PB3)
/MOSI: J3.4, U1.10 ((MOSI)PB2)
/SCK: J3.3, U1.9 ((SCK)PB1)
/SCL/D3: P4.3, R2.2, U1.18 (~~(INT0/SCL)PD0)
/SDA: P1.2, P4.4, R1.2, U1.19 ((INT1/SDA)PD1)
/WD2812-in: P3.2, U1.41 ((A0)PF0)
/buzz: R3.1, U1.31 (~~PC6)
/col0: SW1.1, SW7.1, SW13.1, SW19.1, U1.40 ((A1)PF1)
/col1: SW2.1, SW8.1, SW14.1, SW20.1, U1.39 ((A4)PF4)
/col2: SW3.1, SW9.1, SW15.1, SW21.1, U1.33 (PE2)
/col3: SW4.1, SW10.1, SW16.1, SW22.1, U1.30 (~~(A13)PB6)
/col4: SW5.1, SW11.1, SW17.1, SW23.1, U1.27 (~~(ADC10)PD7)
/col5: SW6.1, SW12.1, SW18.1, SW24.1, U1.26 (~~(ADC9)PD6)
/row0: D1.1 (K), D5.1 (K), D9.1 (K), D13.1 (K), D17.1 (K), D21.1 (K), U1.38 ((A5)PF5)
/row1: D2.1 (K), D6.1 (K), D10.1 (K), D14.1 (K), D18.1 (K), D22.1 (K), U1.37 ((A6)PF6)
/row2: D3.1 (K), D7.1 (K), D11.1 (K), D15.1 (K), D19.1 (K), D23.1 (K), U1.32 (~~PC7)
/row3: D4.1 (K), D8.1 (K), D12.1 (K), D16.1 (K), D20.1 (K), D24.1 (K), U1.36 ((A7)PF7)
/~RESET: J2.2, J3.5, R6.1, U1.13 (~RESET~)
GND: C1.2, C2.2, C3.2, C4.2, J1.2, J2.1, J3.6, P1.3, P2.5 (GND), P2.6 (shield), P3.3, P4.1, U1.5 (UGND), U1.15 (GND), U1.23 (GND), U1.35 (GND), U1.43 (GND), U1.TAB (GND)
unnamed: C2.1, U1.17 (XTAL1), Y1.1
unnamed: C3.1, U1.16 (XTAL2), Y1.2
unnamed: C4.1, U1.6 (UCap)
unnamed: D1.2 (A), SW1.2
unnamed: D2.2 (A), SW7.2
unnamed: D3.2 (A), SW13.2
unnamed: D4.2 (A), SW19.2
unnamed: D5.2 (A), SW2.2
unnamed: D6.2 (A), SW8.2
unnamed: D7.2 (A), SW14.2
unnamed: D8.2 (A), SW20.2
unnamed: D9.2 (A), SW3.2
unnamed: D10.2 (A), SW9.2
unnamed: D11.2 (A), SW15.2
unnamed: D12.2 (A), SW21.2
unnamed: D13.2 (A), SW4.2
unnamed: D14.2 (A), SW10.2
unnamed: D15.2 (A), SW16.2
unnamed: D16.2 (A), SW22.2
unnamed: D17.2 (A), SW5.2
unnamed: D18.2 (A), SW11.2
unnamed: D19.2 (A), SW17.2
unnamed: D20.2 (A), SW23.2
unnamed: D21.2 (A), SW6.2
unnamed: D22.2 (A), SW12.2
unnamed: D23.2 (A), SW18.2
unnamed: D24.2 (A), SW24.2
unnamed: J1.1, R3.2
unnamed: JP1.2, R1.1
unnamed: JP2.2, R2.1
unnamed: P2.2 (D-), R4.1
unnamed: P2.3 (D+), R5.1
VBUS: C1.1, J3.2, JP1.1, JP2.1, P1.1, P2.1 (VCC), P3.1, P4.2, R6.2, U1.2 (UVCC), U1.7 (VBUS), U1.14 (VCC), U1.24 (AVCC), U1.34 (VCC), U1.44 (AVCC)

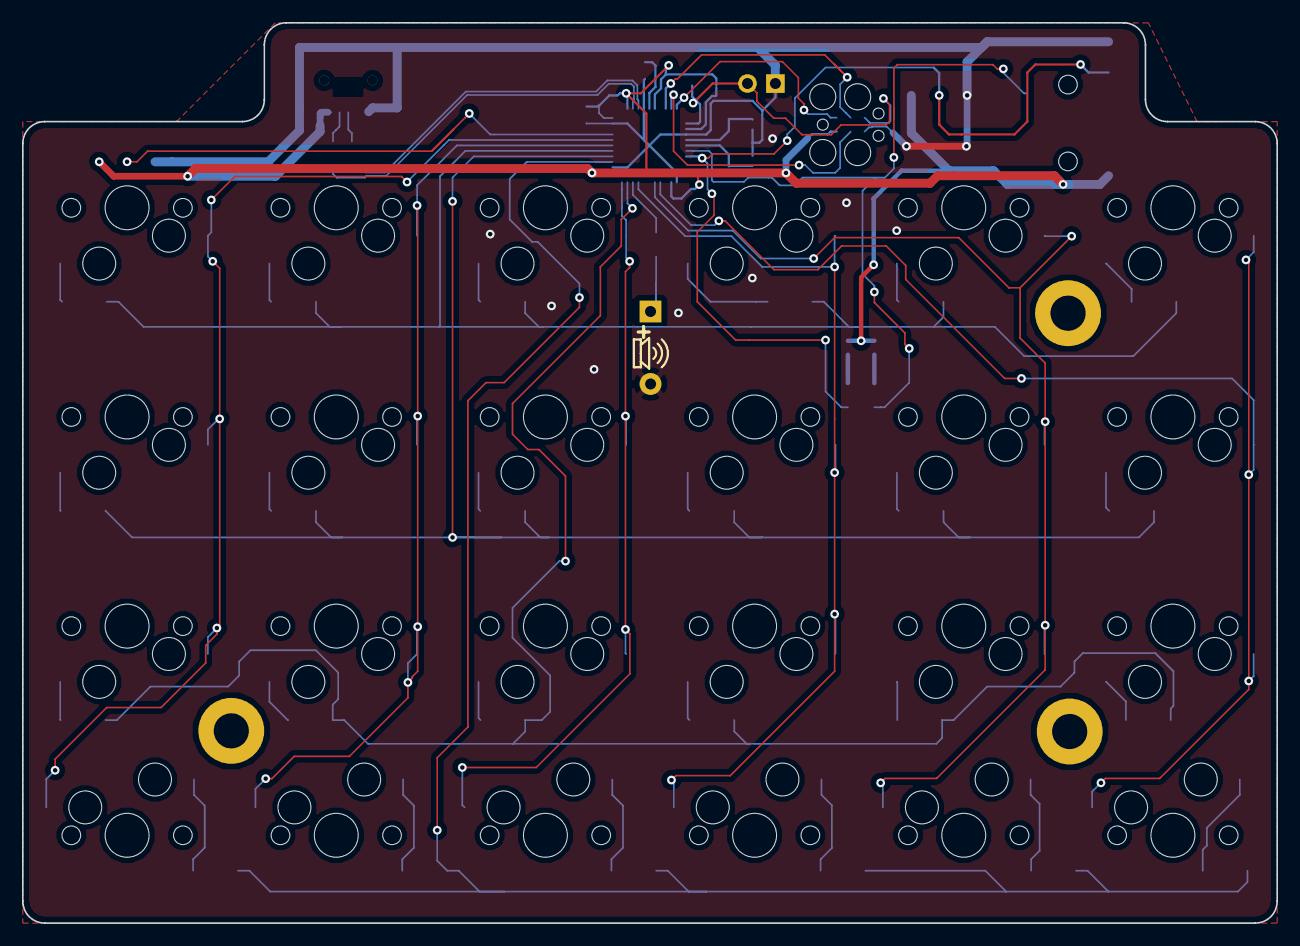
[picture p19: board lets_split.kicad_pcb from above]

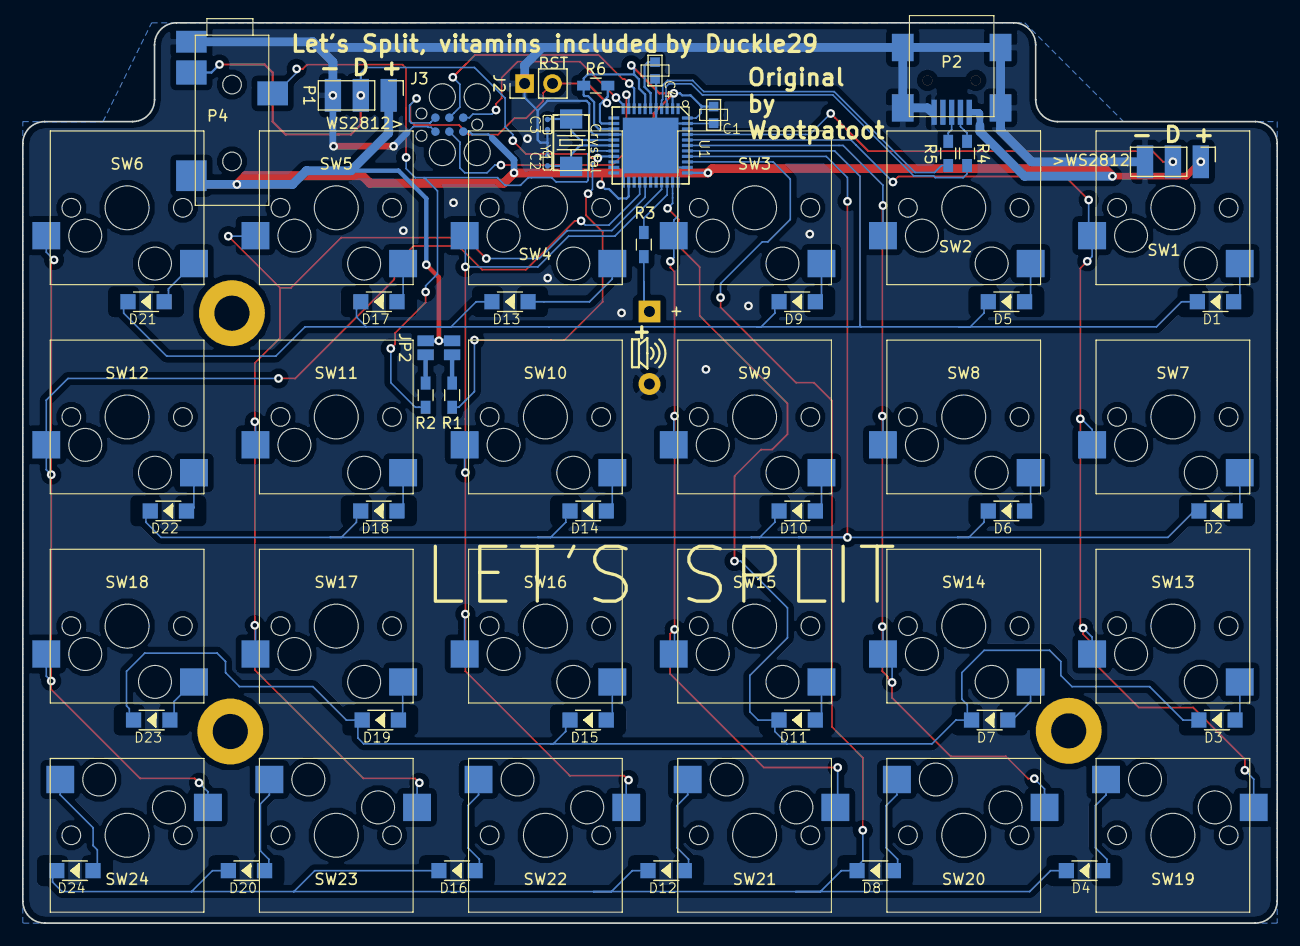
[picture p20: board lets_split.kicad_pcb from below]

Board: 2 copper layers, 114.2 x 82.0 mm, 69 parts (45 on the bottom side), 54 nets.

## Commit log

2017-10-10 Changed to use kailh sockets, start of branch
    [lets_split.sch]
2017-10-10 Finished desing
    [lets_split-R.kicad_pcb, lets_split-RL-panel.kicad_pcb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]
2017-10-10 Added zipped gerber and renders
    [lets_split-RL-panel.kicad_pcb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]
2017-10-10 Removed old gerbers
    [lets_split-B.Cu.gbr, lets_split-B.Mask.gbr, lets_split-B.SilkS.gbr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]
2017-10-10 flipped TRRS connector the the back for both boards
    [lets_split-RL-panel.kicad_pcb]
2017-10-10 Moved panel files into subfolder
    [lets_split-R.kicad_pcb, lets_split-RL-panel.kicad_pcb, lets_split.kicad_pcb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]
2017-10-10 V3 version, with mini usb added
    [lets_split-RL-panel.kicad_pcb, lets_split.kicad_pcb, lets_split.sch]
2017-10-10 Finished and panelized V3
    [lets_split-RL-panel.kicad_pcb, lets_split.kicad_pcb, lets_split.sch]
2017-10-12 Changed to actually aquireable TRRS connector
    [lets_split-RL-panel.kicad_pcb, lets_split.kicad_pcb, lets_split.sch]
2017-10-12 Actually saved PCB to new TRRS socket
    [lets_split.kicad_pcb]
2017-10-12 Increased powertraces thickness to TRRS socket
    [lets_split-RL-panel.kicad_pcb, lets_split.kicad_pcb]
2017-10-12 Panelized design with new connector
    [lets_split-RL-panel.kicad_pcb]
2017-10-12 Finished up lettering on the panel
    [lets_split-RL-panel.kicad_pcb, lets_split.kicad_pcb]
2017-10-14 Added SVG of schematic
2017-10-14 Made image a link to schematic
2017-10-17 Switched to using diode footprints with actual silk screen, and moved dioes away from socket pads
    [lets_split.kicad_pcb, lets_split.sch]
2017-10-17 Moved silkscreen around a bit
    [lets_split.kicad_pcb]
2017-10-17 Routed board with reversible socket footprint, and mirrored connectors
    [lets_split.kicad_pcb, lets_split.sch]
2017-10-17 Added images of reversible version
    [lets_split-RL-panel.kicad_pcb, lets_split.kicad_pcb, lets_split.sch]
2017-10-17 Updated schematic svg
    [lets_split.kicad_pcb]
2017-10-17 Removed the whitespace from the schematic svg
2017-10-17 Added speaker output to the board
    [lets_split.kicad_pcb, lets_split.sch]
2017-10-17 Added gerbers
    [lets_split-B.Cu.gbr, lets_split-B.Mask.gbr, lets_split-B.SilkS.gbr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]
2017-10-17 Connected speaker to correct pin
    [lets_split-B.Cu.gbr, lets_split-B.Mask.gbr, lets_split-B.SilkS.gbr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]
2017-10-17 Fixed some stupid mistakes (traces over holes)
    [lets_split.kicad_pcb, lets_split.sch]
2017-10-17 Good night
    [lets_split.kicad_pcb]
2017-10-17 Good night I said
    [lets_split.sch]
2017-10-18 Before adding cherrymx 3D model
    [lets_split.kicad_pcb]
2017-10-18 Added some 3D models and new renderse
    [lets_split.kicad_pcb]
2017-10-19 Changed 3D file path
    [lets_split.kicad_pcb]
2017-10-19 Going home
    [lets_split.kicad_pcb]
2017-10-22 Re-poured copper
    [lets_split.kicad_pcb]
2017-10-23 Did a few small changes to routing
    [lets_split.kicad_pcb]
2017-10-23 Fixed a broken gnd path
    [lets_split.kicad_pcb]
2017-10-25 Added speaker symbol
    [lets_split.kicad_pcb]
2017-10-26 Changed footpring designations for possible PCBA in the future
    [lets_split.kicad_pcb, lets_split.sch]
2017-11-14 Moved TRRS connector to clear switches
    [lets_split.kicad_pcb]
2017-11-15 First commit for mcu version
    [lets_split.kicad_pcb]
2017-11-16 Vitamins included "done"
    [lets_split.kicad_pcb, lets_split.sch]
2017-11-16 I love git. Saved PCB file, started panel work
    [BOM.xls, left.sch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]
2017-11-16 Finished panel
    [BOM.xls, left.sch, lets_split.kicad_pcb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]
2017-11-19 Made routed panel
    [lets_split_panel.kicad_pcb]
2017-11-22 Added test jig for panel
    [BOM.xls, BOM2.xls, BOMseeed.xls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]
2017-11-23 Changed to use SOT-23 dual diodes for cost
    [left.sch, lets_split_panel.kicad_pcb, right.sch]
2017-11-23 Added 3D models
    [lets_split_panel.kicad_pcb, pcb.step]
2017-11-23 Added option for 2U spacebars
    [lets_split_panel.kicad_pcb]
2017-11-28 made sure USB datalines had gnd under them
    [lets_split_panel.kicad_pcb]
2017-11-28 Re-rendered images
    [lets_split_panel.kicad_pcb]
2017-11-29 Added fancy :)
    [left.sch, lets_split_panel.kicad_pcb, prog-jig.kicad_pcb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]
2017-12-05 Finished programming jig
    [BOM.xls, lets_split_panel.kicad_pcb, prog-jig.kicad_pcb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]
2017-12-05 Removed Programming-jig and test jig
    [Test-jig.kicad_pcb, Test-jig.sch, lets_split_righthalfpanel.stp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]
2017-12-07 updated gerbers
    [lets_split_panel.kicad_pcb]
2017-12-07 Seperated gerbers on request from board house
    [left.sch, lets_split_panel.kicad_pcb, right.sch]
2017-12-19 Added PnP files and split gerbers
    [left.sch, lets_split_panel.kicad_pcb, lets_split_panel.sch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]
2018-01-11 Added kiwi
    [lets_split_panel.kicad_pcb, lets_split_panel.sch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]
2018-01-14 Added BOM
    [BOM.csv, BOM.xls, BOM2.xls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]
